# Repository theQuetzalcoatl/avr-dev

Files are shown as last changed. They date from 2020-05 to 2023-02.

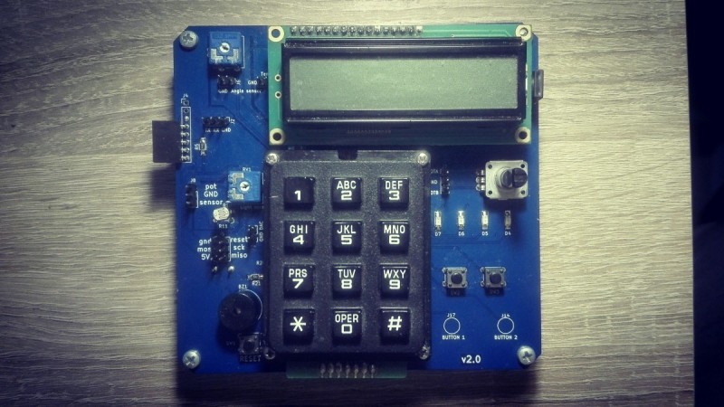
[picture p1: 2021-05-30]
HW/pictures/v2_0_full.jpg

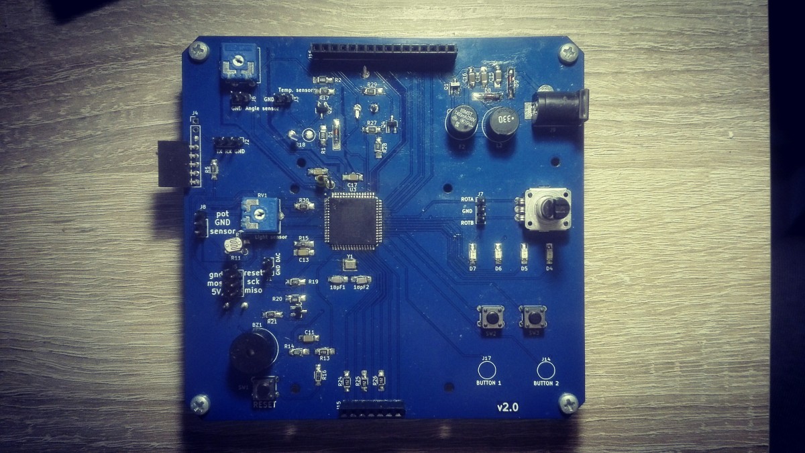
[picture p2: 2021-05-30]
HW/pictures/v2_0_nude.jpg

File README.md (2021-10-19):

# avr-dev

A self made and designed embedded development board with several peripherals/devices to use. On top of that is an embedded kernel with several device drivers, forming an OS.</br>
The project aims to develop a suitable SW architecture and a corresponding HW development board, which can be the foundation of learning and experimentation.

### [Hardware](https://github.com/theQuetzalcoatl/avr-dev/blob/master/HW/README.md "Hardware"):

* LCD
* DAC
* Buzzer
* LEDs & buttons
* Keypad
* UART (potentially USB)
* Temperature sensing
* Light sensing
* Capacitive touch sensing
* Voltage/angle sensing
* Rotary encoder

### [Software](https://github.com/theQuetzalcoatl/avr-dev/blob/master/SW/Application/README.md "Software"):

* A primitive, embedded OS
* Device drivers for HAL
* Application

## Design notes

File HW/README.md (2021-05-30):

# Hardware

This file is intended to keep track and present the more detailed informations about the HW part of the project.
The PCB is currently developed in KiCAD. 
---
### HW elements:
* **DAC**: A first order RC low pass filter with variing duty cycle PWM on its input
* **LCD**: A 2x16 display. Backlight can be switched on/off by SW
* **Buzzer**: MOSFET switched, frequency can be set by SW
* **LEDS & buttons**: 4 leds, two push buttons without external pullup resistors
* **Keypad**: a simple 3 by 4 one</br>
      |1|2|3|</br>
      |4|5|6|</br>
      |7|8|9|</br>
      |*|0|#|</br>
* **UART**: Jumper pins for UART  communication, with a suitable connector USB is possible using the CH340G based USB/UART module
* **Temp sensing**: A PT1000 and a current source is used
* **Light sensing**: An LDR is used alongside a regular pot. meter so treshold can also be set
* **Capacitive touch sensing**: Two buttons are made with using only one GPIO each
* **Voltage/angle sensing**: A regular pot meter will supply the devided Vcc voltage. It can be turned and as such, can be used as an angle sensor
* **Rotary encoder**: Capacitors are placed on the MCU pins to help with debouncing

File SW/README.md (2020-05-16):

# Software

This file is intended to keep track of and present the more detailed informations about the SW part of the project.
Explanation of folder structure, compilation how to etc... will be discussed here.
---
### Versioning: *TBD*

### How to compile:

#### known bugs, errors:

### Coding guideline:

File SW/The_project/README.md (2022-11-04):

**Versioning**: 

Right now somewhat arbitrary, but a **major.minor** is being used</br>
*major*: The change forces the user to use the SW a different way. E.g. A feature is cut, an API has changed, new build environment etc.</br>
*minor*: Changes may not directly affect the user. E.g. Bugfixes, efficiency improvement, internal restructuring etc.

**How to compile**:</br>
*  ./build.sh        (only compilation)</br>
*  ./build.sh upload (for burning as well)
___
### Aztec</br>
A lightweight, monolithic, real time embedded OS for AVR chips.
* Preemptive, using time slicing scheduling(Round Robin)
* Configurable stack size for each thread
* Stack overflow detection
* Device driver integration for the HW
* Currently 10 system calls
* Scripts for better, safer code quality
* Relatively configurable
* Mistake-proof</br>
  * stack sizes are checked for minimum & maximum
  * cannot register multiple threads using the same stack
  * min. max. system tick check, based on pysical calculations

#### Driver system</br>

##### **Related syscalls, functions**:
* _register_device_ - initializes and notifies the kernel of its existance, provides init checking upon leasing and ownership handling
* _lease_ - checks device initialization and its owner. If not owned it will be by the calling thread, if owned, an error will be raised by the kernel
* _release_ - tries to release the requested device. If the caller own it, it will be released, if not, error.
    If a thread exits without releasing any of its owned devices, the kernel releases them.
* _check_device_ownership_ - the developer of a driver can guard function calls to a device by checking the caller's ownership. It is not necessary, though.</br></br>
**Prepare a device for registration** by creating a directory under 'drivers'. Create at least an initialization function for it with type void and no arguments, and lastly, add a device ID entry to the DEVICES_IDS enum in kernel.h and include the header file.

#### Notice
More threads and longer systick period lessen the wait syscalls' accuracy.</br>
Due to required minimal stack usage the theoritical absolute maximum number of threads is about 89.</br>
Each Thread's stack usage should be estimated by the user.</br>
Threads should be exited with the proper syscall and not with a **return** statement.</br>

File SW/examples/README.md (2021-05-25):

**How to compile:**
	$ ./build_n_burn.sh <sourcefile_name>
	
**example:**
	$ ./build_n_burn.sh buttons.c

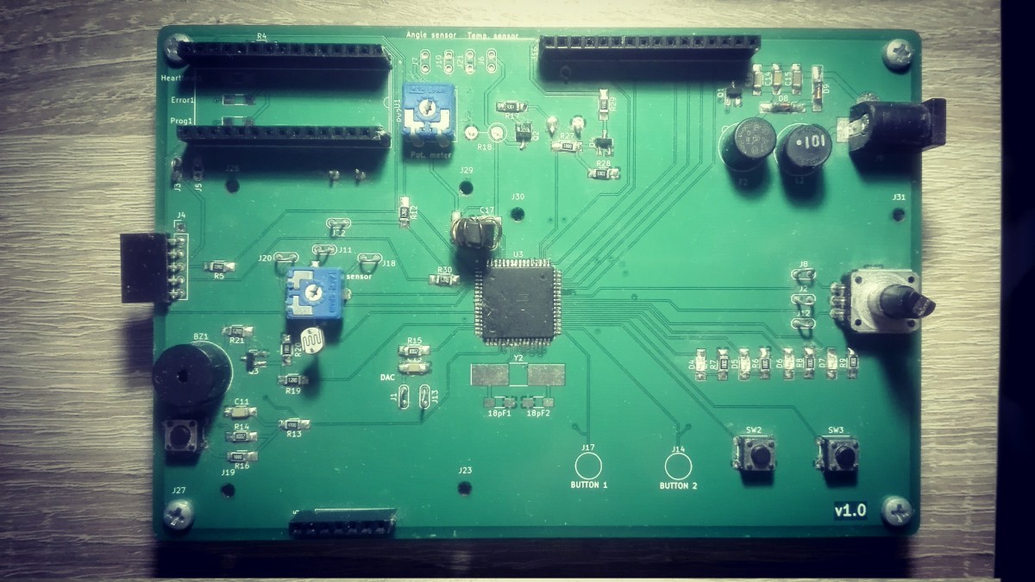
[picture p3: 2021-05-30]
HW/pictures/v1_0_nude.jpg

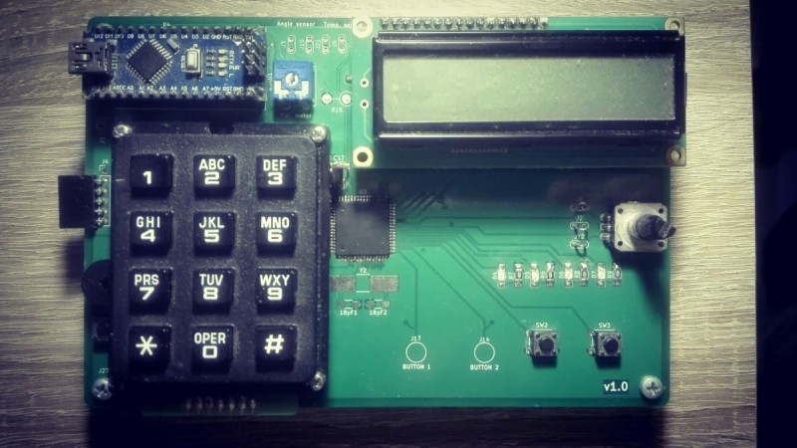
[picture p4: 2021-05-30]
HW/pictures/v1_0_full.jpg

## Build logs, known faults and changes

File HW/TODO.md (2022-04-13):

* [x] Make the corners round
* [x] Add version on silkscreen
* [x] Mark pin 1 of ICs with different pad than the others
* [x] Make all leds consume about 10-15 mA
* [x] Change pins of every button to fit into footprint
* [x] Low ohm resistors to the USART signals, to reduce possible crosstalk
* [-] Elongate the main MCU pads for easier soldering + easier removing of solder bridges.
* [x] Eliminate most of the  90° traces

---------------- v2.0 ----------------------

* [x] Separate Arduino programmer from the board, only SPI connectrions shall remain
* [x] Change the connector pinout to the USB/UART module to have it 5V
* [x] Change position of C17,C9 and L1
* [x] Use one resistor for Tx pin insted of R30 and R12
* [x] Rotary encoder's case shall be grounded
* [x] Led resistors to the back side
* [x] Separate the analogue circuitries from each other.
* [x] Change the GND and VCC planes.
* [x] 5V Jack connector side fuse shall be placed before the zener diodes
* [-] Delete the voltage/angle sensor, a.k.a. pot meter and the one which is used for Analoge Comparison should be moved to one of the ADC multiplexer pins so it can be used for both.
			Additionally, the placement of the pot. meter should be considered as it may get a handle or something. 
* [x] Add Zner diode + resistor to tie the BJT's base to a lower voltage level in order to be able to function as current generator
* [-] Re-order the pinout to the keyboard
* [x] Reverse the order of leds to be able to visually represent binariy counting bits etc.. because right now it is backwards

---------------- v3.0 ----------------------

* [-] Shrink the ground connection to the PT1000 in order to make it able to represent the *air's* temperature - not so critical, besides, PCB temp is much more stable
* [x] Male headers in series with DC jack input to be able to measure input current.
* [x] Create a proper footprint for the UART 90° connector.
* [-] Push buttons shall be SMD
* [X] Insert LED1..LED4 for leds instead of D4..D7
* [x] Add a 4 pin male header connected to GND for easier access to GND.
* [x] Remove D9 Zener diode because it is eesentially not needed when it comes to negative input voltage
* [x] Replace input DC jack connector with an USB one.

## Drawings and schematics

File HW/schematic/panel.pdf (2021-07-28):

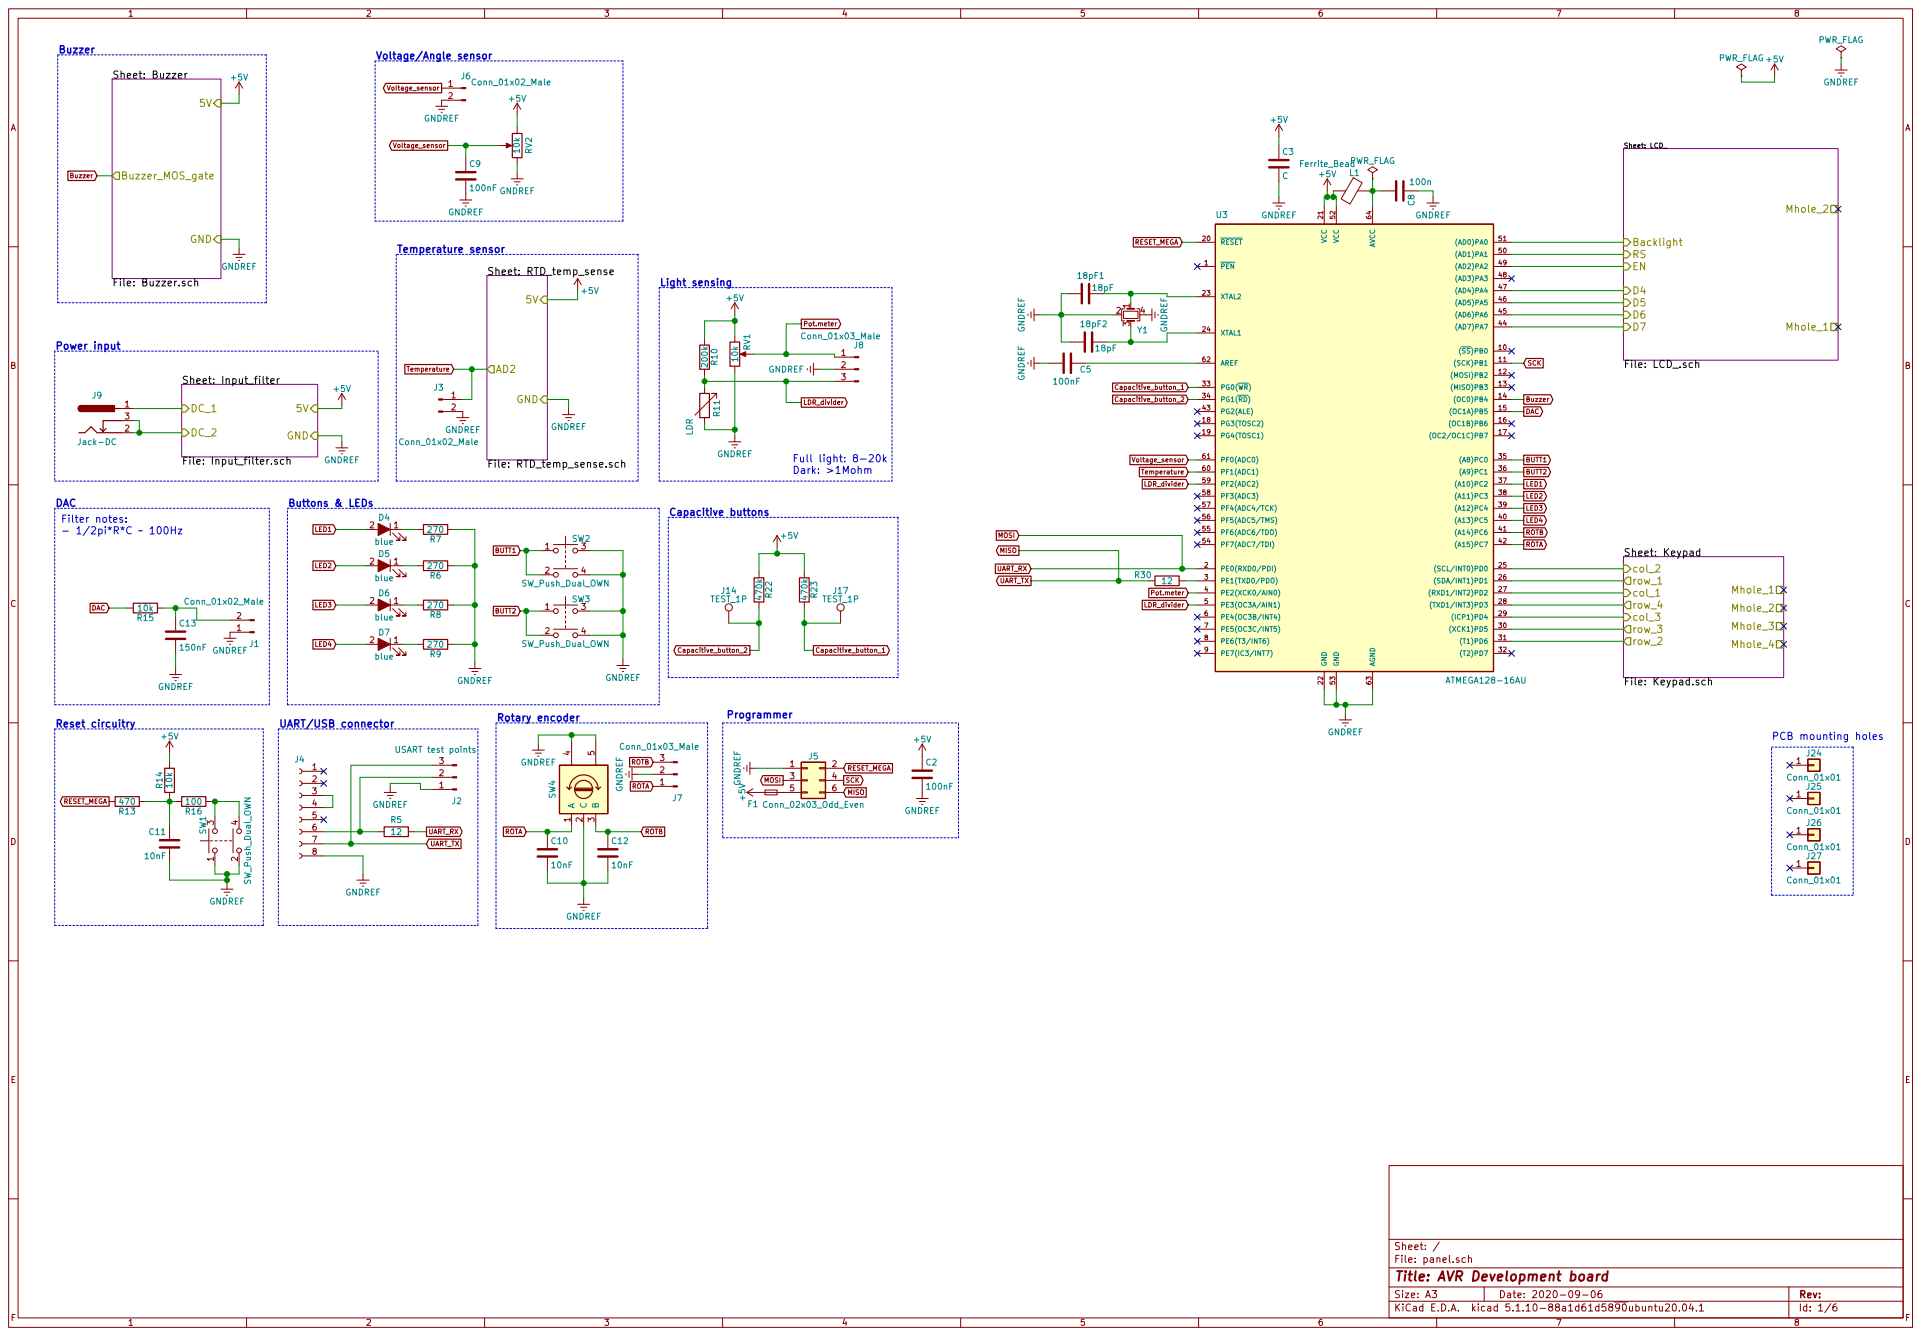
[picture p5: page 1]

Sheet: Buzzer File: Buzzer.sch Buzzer_MOS_gate
J7 Conn_01x03_Male GNDREF GNDREF

File: panel.sch Sheet: /
Id: 1/6 Title: AVR Development board

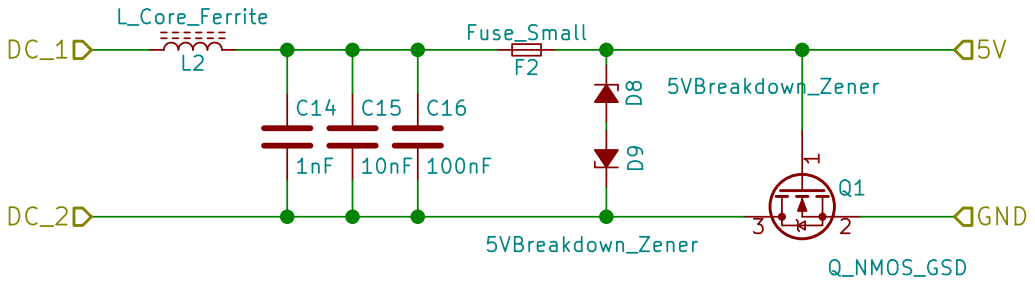
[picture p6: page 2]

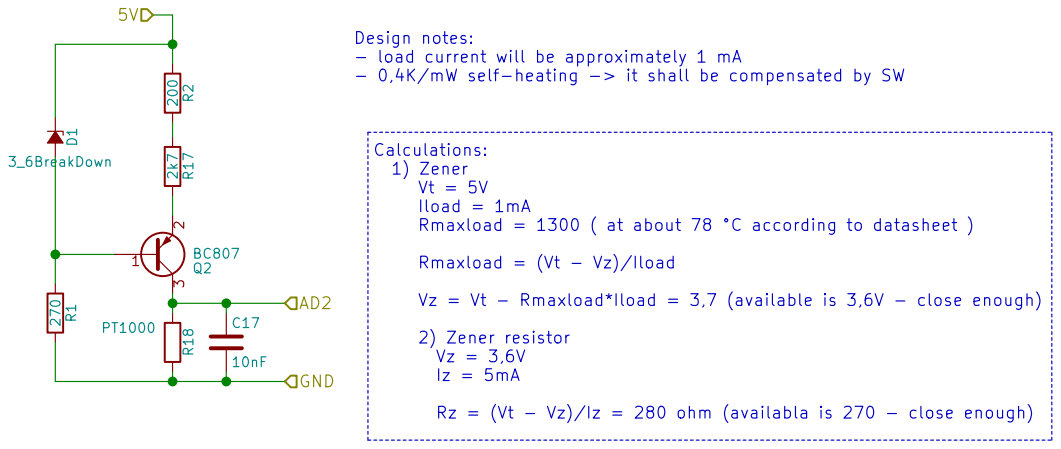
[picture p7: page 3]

Design notes:
- load current will be approximately 1 mA
- 0,4K/mW self-heating -> it shall be compensated by SW

1) Zener
Iload = 1mA
Rmaxload = 1300 ( at about 78 °C according to datasheet )

Rmaxload = (Vt - Vz)/Iload

Vz = Vt - Rmaxload*Iload = 3,7 (available is 3,6V - close enough)

Rz = (Vt - Vz)/Iz = 280 ohm (availabla is 270 - close enough)

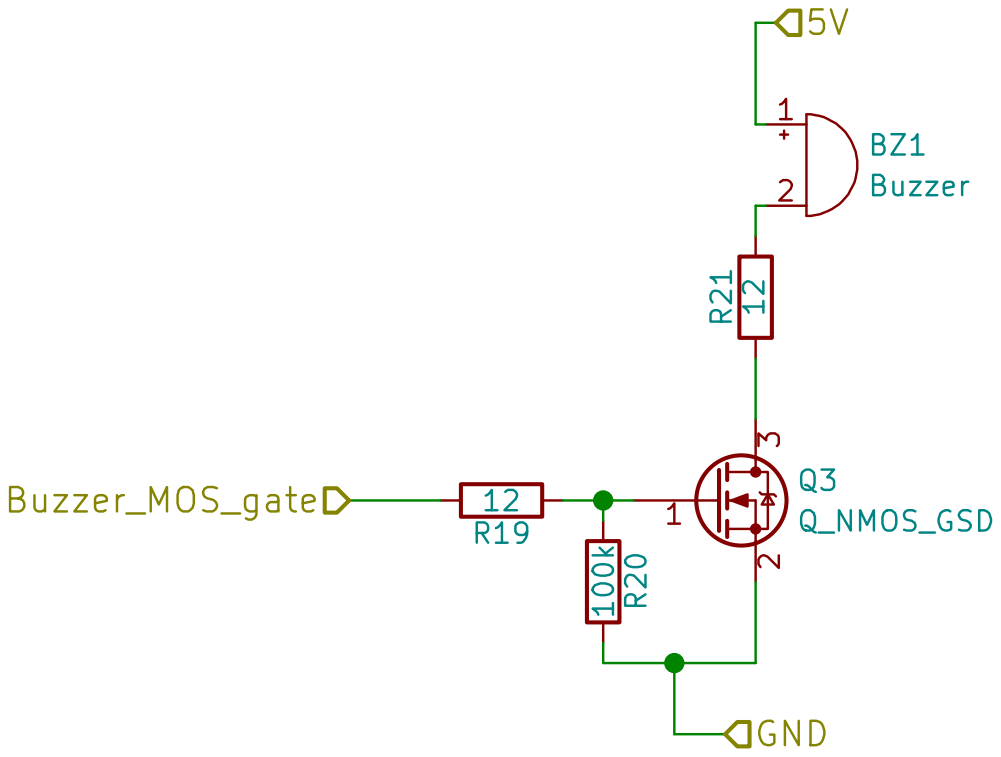
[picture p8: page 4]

Id: 4/6 Title: File: Buzzer.sch Sheet: /Buzzer/

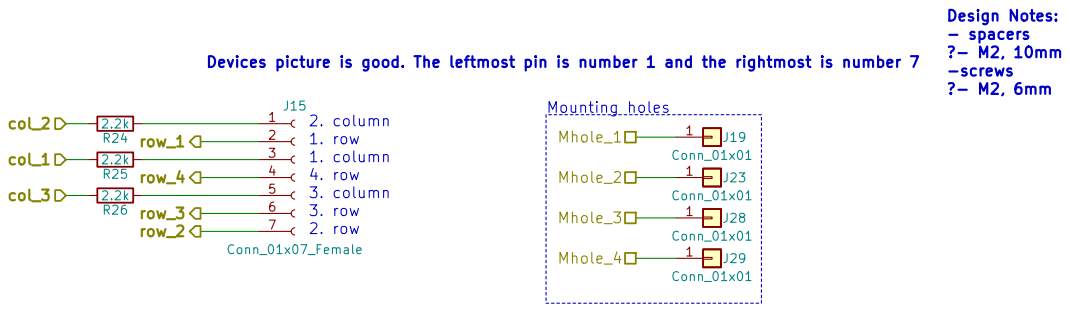
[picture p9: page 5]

Devices picture is good. The leftmost pin is number 1 and the rightmost is number 7

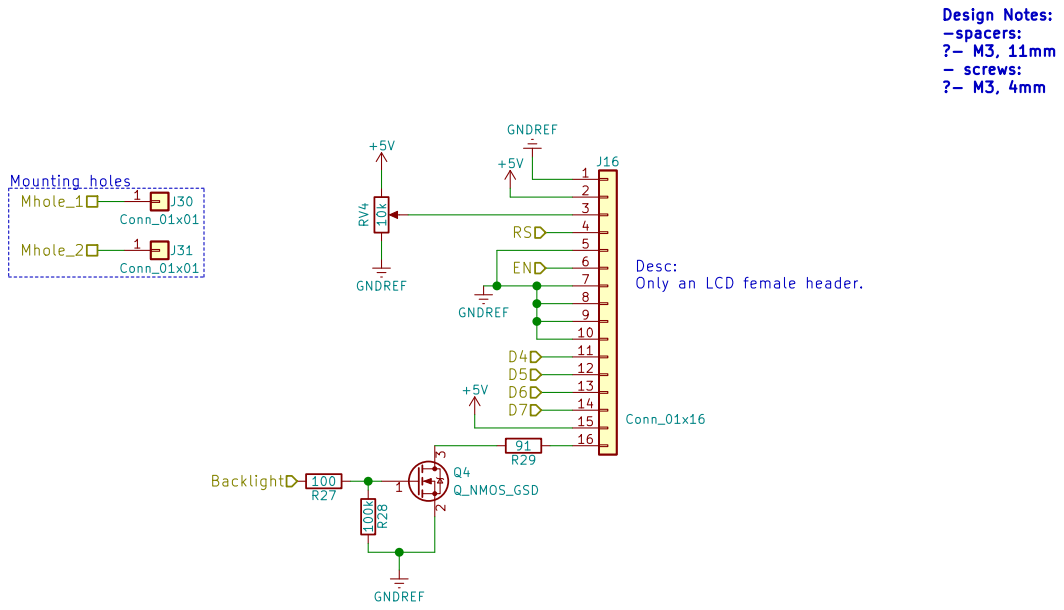
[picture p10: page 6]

Desc: Only an LCD female header.

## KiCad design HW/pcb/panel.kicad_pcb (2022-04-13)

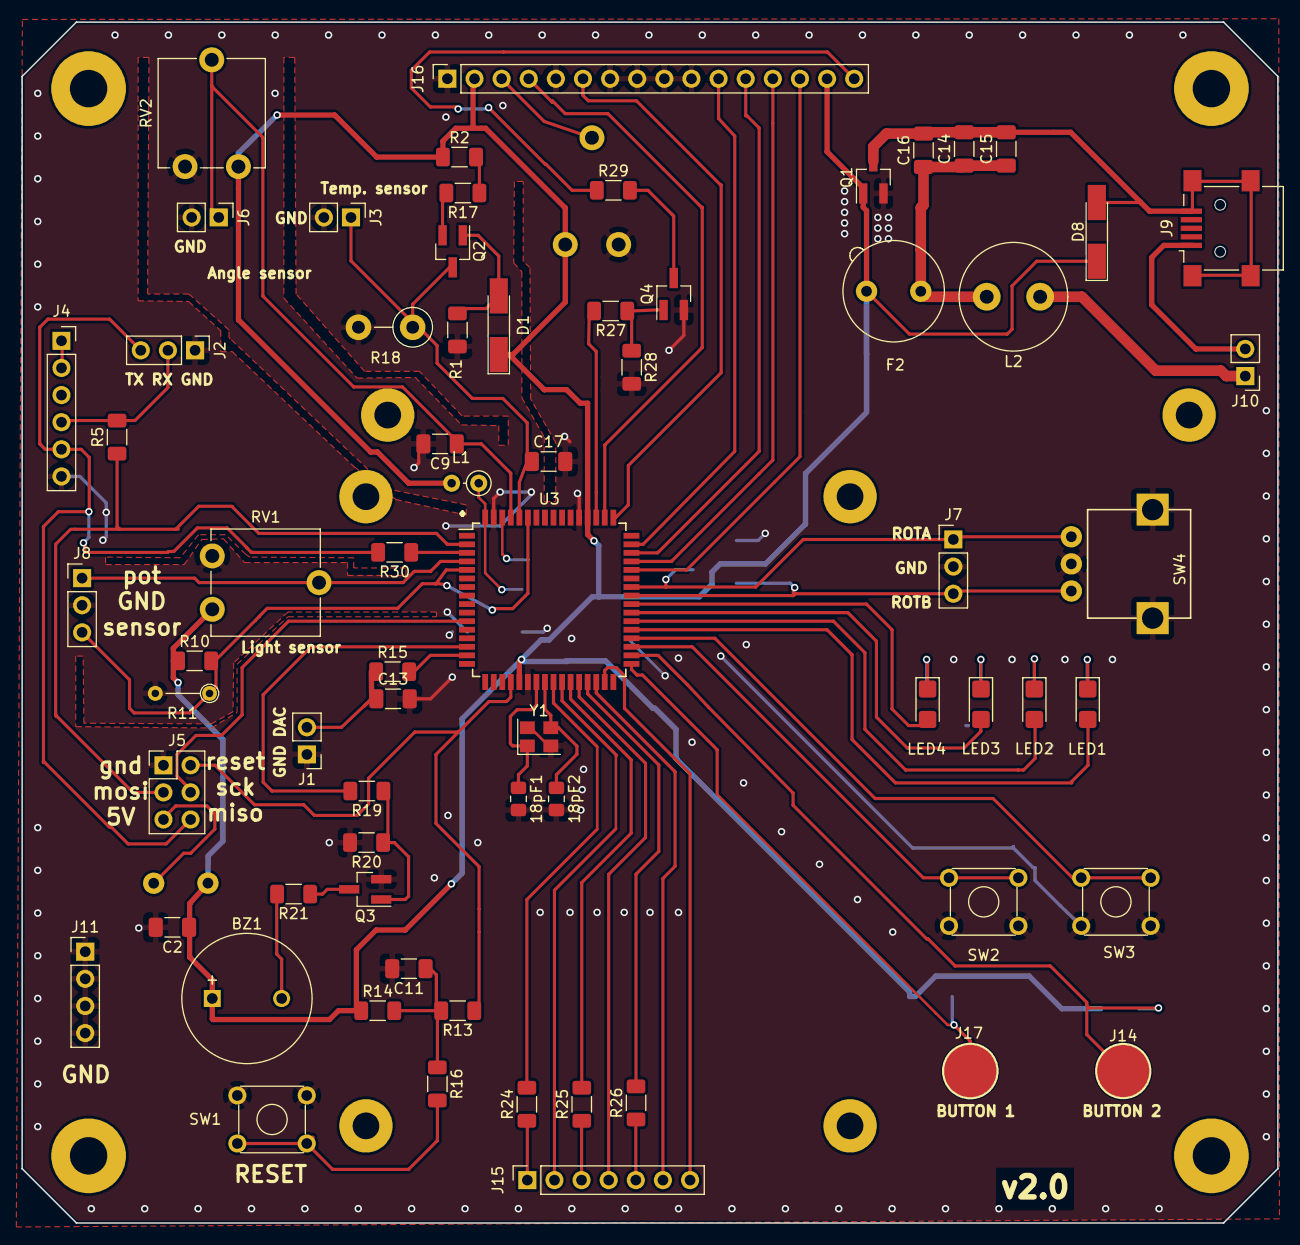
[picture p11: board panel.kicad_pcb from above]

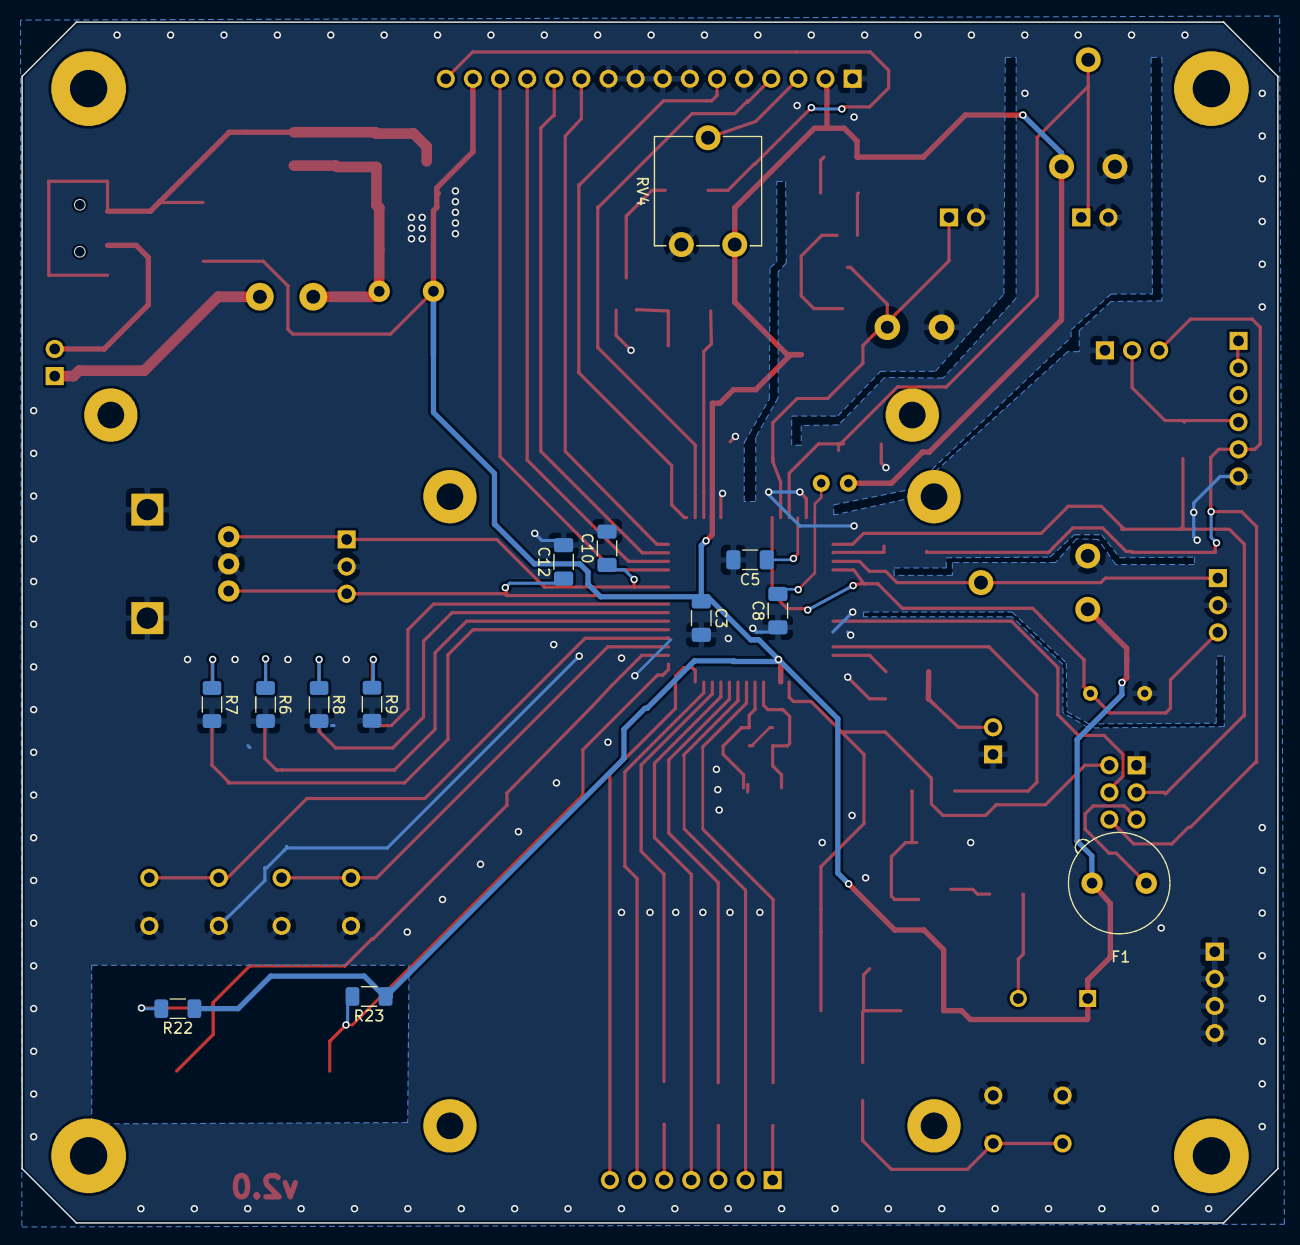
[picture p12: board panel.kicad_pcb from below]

Board: 2 copper layers, 117.6 x 112.5 mm, 91 parts (13 on the bottom side), 68 nets.

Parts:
18pF1, 18pF2: 18pF; C_0805_2012Metric_Pad1.18x1.45mm_HandSolder
BZ1: Buzzer; MagneticBuzzer_ProSignal_ABT-410-RC
C2, C5, C9, C16: 100nF; C_1206_3216Metric_Pad1.33x1.80mm_HandSolder
C3: C; C_1206_3216Metric_Pad1.33x1.80mm_HandSolder
C8: 100n; C_1206_3216Metric_Pad1.33x1.80mm_HandSolder
C10, C11, C12, C15, C17: 10nF; C_1206_3216Metric_Pad1.33x1.80mm_HandSolder
C13: 150nF; C_1206_3216Metric_Pad1.33x1.80mm_HandSolder
C14: 1nF; C_1206_3216Metric_Pad1.33x1.80mm_HandSolder
D1: 3_6BreakDown; D_MiniMELF_Handsoldering
D8: 5VBreakdown_Zener; D_MiniMELF_Handsoldering
F1, F2: Fuse_Small; Fuseholder_Fuse_TR5_Littlefuse-No560_No460
J1, J6: Conn_01x02_Male; PinHeader_1x02_P2.54mm_Vertical
J2: USART test points; PinHeader_1x03_P2.54mm_Vertical
J3: Conn_01x02_Male; Pin_Header_Straight_1x02_Pitch2.54mm
J4: uart_conn; PinSocket_1x06_P2.54mm_Vertical
J5: Conn_02x03_Odd_Even; PinHeader_2x03_P2.54mm_Vertical
J7, J8: Conn_01x03_Male; PinHeader_1x03_P2.54mm_Vertical
J9: USB_B_Mini; USB_Mini-B_Lumberg_2486_01_Horizontal
J10: current sense; PinHeader_1x02_P2.54mm_Vertical
J11: GND conn; PinHeader_1x04_P2.54mm_Vertical
J14, J17: TEST_1P; Measurement_Point_Round-SMD-Pad_Big
J15: Conn_01x07_Female; PinSocket_1x07_P2.54mm_Vertical
J16: Conn_01x16; PinSocket_1x16_P2.54mm_Vertical
J19, J23, J28, J29, J30, J31: Conn_01x01; MountingHole_2.5mm_Pad
J24, J25, J26, J27: Conn_01x01; MountingHole_3.5mm_Pad
L1: Ferrite_Bead; L_Axial_L5.3mm_D2.2mm_P2.54mm_Vertical_Vishay_IM-1
L2: L_Core_Ferrite; L_Radial_D10.0mm_P5.00mm_Fastron_07M
LED1, LED2, LED3, LED4: blue; LED_1206_3216Metric_Castellated
Q1, Q3, Q4: Q_NMOS_GSD; SOT-23_Handsoldering
Q2: BC807; SOT-23_Handsoldering
R1, R6, R7, R8, R9: 270; R_1206_3216Metric_Pad1.30x1.75mm_HandSolder
R2: 200; R_1206_3216Metric_Pad1.30x1.75mm_HandSolder
R5, R19, R21, R30: 12; R_1206_3216Metric_Pad1.30x1.75mm_HandSolder
R10: 200k; R_1206_3216Metric_Pad1.30x1.75mm_HandSolder
R11: LDR; R_Axial_DIN0204_L3.6mm_D1.6mm_P5.08mm_Vertical
R13: 470; R_1206_3216Metric_Pad1.30x1.75mm_HandSolder
R14, R15: 10k; R_1206_3216Metric_Pad1.30x1.75mm_HandSolder
R16, R27: 100; R_1206_3216Metric_Pad1.30x1.75mm_HandSolder
R17: 2k7; R_1206_3216Metric_Pad1.30x1.75mm_HandSolder
R18: PT1000; R_Axial_DIN0411_L9.9mm_D3.6mm_P5.08mm_Vertical
R20, R28: 100k; R_1206_3216Metric_Pad1.30x1.75mm_HandSolder
R22, R23: 470k; R_1206_3216Metric_Pad1.30x1.75mm_HandSolder
R24, R25, R26: 2.2k; R_1206_3216Metric_Pad1.30x1.75mm_HandSolder
R29: 91; R_1206_3216Metric_Pad1.30x1.75mm_HandSolder
RV1, RV2, RV4: 10k; Potentiometer_ACP_CA9-V10_Vertical
SW1, SW2, SW3: SW_Push_Dual_OWN; SW_TH_Tactile_Omron_B3F-10xx
SW4: Rotary_Encoder_With_CaseHolder; Rotary_Encoder_CaseHolder
U3: ATMEGA128-16AU; TQFP-64_14x14mm_P0.8mm
Y1: Crystal_GND24_Small; Crystal_SMD_3225-4Pin_3.2x2.5mm

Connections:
+5V: BZ1.1, C2.1, C3.1, D1.1, D8.1, F1.2, F2.2, J16.2, J16.15, L1.2, Q1.1, R2.1, R10.1, R14.1, R22.1, R23.1, RV1.1, RV2.1, RV4.1, U3.21, U3.52
/Input_filter/DC_1: J9.1, J10.2
/Input_filter/DC_2: C14.2, C15.2, C16.2, D8.2, J9.5, J9.6, Q1.3
/Keypad/col_1: R25.2, U3.27
/Keypad/col_2: R24.2, U3.25
/Keypad/col_3: R26.2, U3.29
/Keypad/row_1: J15.2, U3.26
/Keypad/row_2: J15.7, U3.31
/Keypad/row_3: J15.6, U3.30
/Keypad/row_4: J15.4, U3.28
/LCD_/Backlight: R27.2, U3.51
/LCD_/D4: J16.11, U3.47
/LCD_/D5: J16.12, U3.46
/LCD_/D6: J16.13, U3.45
/LCD_/D7: J16.14, U3.44
/LCD_/EN: J16.6, U3.49
/LCD_/RS: J16.4, U3.50
BUTT1: SW2.1, SW2.2, U3.35
BUTT2: SW3.1, SW3.2, U3.36
Buzzer: R19.2, U3.14
Capacitive_button_1: J17.1, R23.2, U3.33
Capacitive_button_2: J14.1, R22.2, U3.34
DAC: R15.2, U3.15
GNDREF: 18pF1.2, 18pF2.2, C2.2, C3.2, C5.2, C8.1, C9.2, C10.2, C11.2, C12.2, C13.2, C17.2, J1.1, J2.1, J3.2, J4.6, J5.1, J6.2, J7.2, J8.2, J11.1, J11.2, J11.3, J11.4, J16.1, J16.5, J16.7, J16.8, J16.9, J16.10, Q1.2, Q3.2, Q4.2, R1.2, R6.2, R7.2, R8.2, R9.2, R11.2, R18.2, R20.2, R28.2, RV1.3, RV2.3, RV4.3, SW1.1, SW1.2, SW2.3, SW2.4, SW3.3, SW3.4, SW4.2, SW4.4, SW4.5, U3.22, U3.53, U3.63, Y1.2, Y1.4
LDR_divider: J8.3, R10.2, R11.1, U3.5, U3.59
LED1: LED1.2, U3.37
LED2: LED2.2, U3.38
LED3: LED3.2, U3.39
LED4: LED4.2, U3.40
MISO: J2.3, J4.5, J5.6, R30.2
MOSI: J5.3, R5.1, U3.2
unnamed: 18pF1.1, U3.23, Y1.1
unnamed: 18pF2.1, U3.24, Y1.3
unnamed: BZ1.2, R21.2
unnamed: C5.1, U3.62
unnamed: C8.2, L1.1, U3.64
unnamed: C11.1, R13.2, R14.2, R16.1
unnamed: C13.1, J1.2, R15.1
unnamed: C14.1, C15.1, C16.1, F2.1, L2.2
unnamed: D1.2, Q2.1, R1.1
unnamed: F1.1, J5.5
unnamed: J2.2, J4.4, R5.2
unnamed: J4.1, J4.2
unnamed: J10.1, L2.1
unnamed: J15.1, R24.1
unnamed: J15.3, R25.1
unnamed: J15.5, R26.1
unnamed: J16.3, RV4.2
unnamed: J16.16, R29.1
unnamed: LED1.1, R7.1
unnamed: LED2.1, R6.1
unnamed: LED3.1, R8.1
unnamed: LED4.1, R9.1
unnamed: Q2.2, R17.2
unnamed: Q3.1, R19.1, R20.1
unnamed: Q3.3, R21.1
unnamed: Q4.1, R27.1, R28.1
unnamed: Q4.3, R29.2
unnamed: R16.2, SW1.3, SW1.4
unnamed: R2.2, R17.1
unnamed: R30.1, U3.3
Pot.meter: J8.1, RV1.2, U3.4
RESET_MEGA: J5.2, R13.1, U3.20
ROTA: C10.1, J7.1, SW4.1, U3.42
ROTB: C12.1, J7.3, SW4.3, U3.41
SCK: J5.4, U3.11
Temperature: C17.1, J3.1, Q2.3, R18.1, U3.60
Voltage_sensor: C9.1, J6.1, RV2.2, U3.61

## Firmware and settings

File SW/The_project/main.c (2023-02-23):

#include "Aztec/kernel/kernel.h"
#include <stdlib.h>
#include <stdbool.h>

/***** Applications *****/

#include "./Applications/heartbeat/heartbeat.h"
#include "./Applications/lcd_backlight_monitor/lcd_backlight_monitor.h"
#include "./Applications/songs/songs.h"

/************************/


register_t kv_stack[CONFIG_MIN_STACK_SIZE + 20];
void display_kernel_version(void)
{
    lease(DEV_LCD);
    lease(DEV_LCD_LIGHT);
    lcd_turn_backligh_on();
    lcd_move_cursor(4,1);
    lcd_print("Aztec "KERNEL_VERSION" ");
    wait_ms(2000);
    lcd_send_command(LCD_CLEAR);
    load(main_heartbeat, heartbeat_stack, sizeof(heartbeat_stack));
    exit_();  // exiting without releasing the LCD -> kernel takes care of it
}

/***********************************************************************/

#define PARENT_MENU  (15u)
#define PRESENT_MENU (16u)
#define ACTION_MENU  (17u)

#define MENU_MARKER_UP   (0u)
#define MENU_MARKER_DOWN (1u)

#define DOWN      KEYPAD_0
#define UP        KEYPAD_5
#define ENTER     KEYPAD_9
#define EXIT      KEYPAD_7
#define ACTIVATE  KEYPAD_8

#define MENU_MARKER "*"

typedef struct menu_point_s
{
    char *name;
    struct menu_point_s *submenu;
    uint8_t type;
    uint8_t is_end;
    uint16_t (*action)(void);
}menu_point_s;


static uint16_t get_systick(void)
{
    return CONFIG_SYSTEM_TICK_IN_US;
}

static uint16_t get_sysclk(void)
{
    return F_CPU/1000000;
}

static uint16_t display_time(void)
{
    char c = 0;
    uint64_t uptime_s = 0;
    uint16_t hours = 0;
    uint8_t minutes = 0;
    uint8_t seconds = 0;
    uint8_t prev_seconds_val = seconds;
    char buffer[4] = {0};

    wait_ms(200); // Needed because otherwise we immideatly escape from the view.

    do{
        uptime_s = get_uptime();;
    
        hours = uptime_s/3600;
        uptime_s -= hours*3600;
    
        minutes = uptime_s/60;
        uptime_s -= minutes*60;

        seconds = uptime_s;

        if(seconds != prev_seconds_val){
            lcd_send_command(LCD_CLEAR);
            lcd_move_cursor(1,1);

            utoa(hours, buffer, 10);
            lcd_print(buffer);
            lcd_print(":");
            utoa(minutes, buffer, 10);
            lcd_print(buffer);
            lcd_print(":");
            utoa(seconds, buffer, 10);
            lcd_print(buffer);

            prev_seconds_val = seconds;
        }
        c = keypad_get_pressed_key_nonblocking();
    }while(c == KEYPAD_NO_NUM);

    return 0;
}

static uint16_t get_threads(void)
{
    return get_num_of_threads();
}

static bool buzzer_is_on = false;
static uint16_t toggle_buzzer_sound(void)
{
    buzzer_is_on = !buzzer_is_on;
    lease(DEV_BUZZER);
    return 0;
}


static uint16_t play_imp_march(void)
{
    release(DEV_BUZZER);
    load(imperial_march, song_stack, sizeof(song_stack));
    return 0;
}

static uint16_t play_tetris(void)
{
    release(DEV_BUZZER);
    load(tetris, song_stack, sizeof(song_stack));
    return 0;
}

static uint16_t play_gta(void)
{
    release(DEV_BUZZER);
    load(gta_sa_theme, song_stack, sizeof(song_stack));
    return 0;
}


register_t menu_stack[CONFIG_MIN_STACK_SIZE + 200];
void menu(void)
{
    wait_ms(1000);
    while(lease(DEV_BUZZER) != NO_ERROR){;}
    while(lease(DEV_LCD) != NO_ERROR){;}

    uint8_t menu_marker_pos = MENU_MARKER_UP;
    uint8_t menu_index = 0;
    char buffer[10] = {0};

    menu_point_s music_submenu[] = {
                                        [0] = {.name = "Imperial March", .type = ACTION_MENU, .action = &play_imp_march, .submenu = 0, .is_end = false},
                                        [1] = {.name = "Tetris", .type = ACTION_MENU, .action = &play_tetris, .submenu = 0, .is_end = false},
                                        [2] = {.name = "GTA SA", .type = ACTION_MENU, .action = &play_gta, .submenu = 0, .is_end = true}
                                    };

    menu_point_s sys_info_submenu[] = {
                                        [0] = {.name = "Threads  - ", .type = PRESENT_MENU, .action = &get_threads, .submenu = 0, .is_end = false},
                                        [1] = {.name = "Systicks - ", .type = PRESENT_MENU, .action = &get_systick, .submenu = 0, .is_end = false},
                                        [2] = {.name = "Clock[MHz] - ", .type = PRESENT_MENU, .action = &get_sysclk, .submenu = 0, .is_end = false},
                                        [3] = {.name = "Uptime        >", .type = ACTION_MENU, .action = &display_time, .submenu = 0, .is_end = true},
                                      };

    menu_point_s keypad_submenu[] = {
                                        [0] = { .name = "On/Off", .type = ACTION_MENU, .action = &toggle_buzzer_sound, .submenu = 0, .is_end = false},
                                        [1] = { .name = " ", .type = ACTION_MENU, .action = 0, .submenu = 0, .is_end = true},
                                    };

    menu_point_s main_menu_points[] = {
                                        [0] = {.name = "Music         >", .type = PARENT_MENU, .action = 0, .submenu = music_submenu, .is_end = false},
                                        [1] = {.name = "System info   >", .type = PARENT_MENU, .action = 0, .submenu = sys_info_submenu, .is_end = false},
                                        [2] = {.name = "Keypad sound  >", .type = PARENT_MENU, .action = 0, .submenu = keypad_submenu, .is_end = false},
                                        [3] = {.name = "Games         >", .type = PARENT_MENU, .action = 0, .submenu = 0, .is_end = true},
                                    };

    menu_point_s *current_menu_point = main_menu_points;

    do{
        lease(DEV_BUZZER); // try to get back buzzer
         /* refresh lcd */
        lcd_send_command(LCD_CLEAR);
        wait_ms(2); /* needed because we can be too fast and print out garbage */
        if(menu_marker_pos == MENU_MARKER_UP){
            lcd_print(MENU_MARKER);
            lcd_print(current_menu_point->name);
            if(current_menu_point->action != 0){
                if(current_menu_point->type == PRESENT_MENU){
                    utoa(current_menu_point->action(), buffer, 10);
                    lcd_print(buffer);
                }
            }
            lcd_move_cursor(2,2);
            lcd_print((current_menu_point+1)->name);
            if((current_menu_point + 1)->action != 0){
                if((current_menu_point + 1)->type == PRESENT_MENU){
                    utoa((current_menu_point + 1)->action(), buffer, 10);
                    lcd_print(buffer);
                }
            }
        }
        else{
            lcd_move_cursor(2,1);
            lcd_print((current_menu_point - 1)->name);
            if((current_menu_point - 1)->action != 0){
                if((current_menu_point - 1)->type == PRESENT_MENU){
                    utoa((current_menu_point - 1)->action(), buffer, 10);
                    lcd_print(buffer);
                }
            }
            lcd_move_cursor(1,2);
            lcd_print(MENU_MARKER);
            lcd_print((current_menu_point)->name);
            if(current_menu_point->action != 0){
                if(current_menu_point->type == PRESENT_MENU){
                    utoa(current_menu_point->action(), buffer, 10);
                    lcd_print(buffer);
                }
            }
        }

        char key = keypad_get_pressed_key();
        switch(key)
        {
            case DOWN:
                if(current_menu_point->is_end == false) {
                    ++menu_index;
                    ++current_menu_point;
                    if(menu_marker_pos == MENU_MARKER_UP) menu_marker_pos = MENU_MARKER_DOWN;
                }
                break;

            case UP:
                if(menu_index > 0){
                    --menu_index;
                    --current_menu_point;
                    if(menu_marker_pos == MENU_MARKER_DOWN) menu_marker_pos = MENU_MARKER_UP;
                }
                break;

            case ENTER:
                if(current_menu_point->type == PARENT_MENU && current_menu_point->submenu != 0){
                    current_menu_point = current_menu_point->submenu;
                    menu_index = 0;
                    menu_marker_pos = MENU_MARKER_UP;
                }
                break;

            case EXIT:
                current_menu_point = main_menu_points;
                menu_index = 0;
                menu_marker_pos = MENU_MARKER_UP;
                break;

            case ACTIVATE:
                if(current_menu_point->action != 0) current_menu_point->action();
                break;
        }

        if(buzzer_is_on){
            buzzer_buzz(350);
            wait_ms(100);
            buzzer_off();
            wait_ms(50);
        }
        else wait_ms(150);
        
    }while(1);
}


/***********************************************************************/


int main(void)
{
    register_device(button_init_device, DEV_BUTTON);
    register_device(led_init_device, DEV_LED1); 
    register_device(led_init_device, DEV_LED2); // multiple init function for different devices
    register_device(led_init_device, DEV_LED3);
    register_device(led_init_device, DEV_LED4);
    register_device(lcd_init_device, DEV_LCD);
    register_device(uart_init_device, DEV_UART);
    register_device(buzzer_init_device, DEV_BUZZER);
    register_device(adc_init_device, DEV_ADC);
    register_device(lcd_init_backlight, DEV_LCD_LIGHT);
    keypad_init_device(); // devices need not be registered by the kernel

    register_thread(display_kernel_version, kv_stack, sizeof(kv_stack));
    register_thread(menu, menu_stack, sizeof(menu_stack));
    register_thread(lcd_backlight_monitor_main, lcd_backlight_monitor_stack, sizeof(lcd_backlight_monitor_stack));

    klog_init(uart_puts);

    klog_log("OH OOH, BIG PROBLEM");

    start_os();

    while(1){;} // just in case
 
    return 0;
}


/***********************************************************************/

/* user defined kernel panic, overwrites the default kernel one */
void kernel_panic(void)
{
    cli();
    DDRC |= 1<<LED3;
    while(1){
        for(uint8_t i = 3; i; --i){
            PORTC |= 1<<LED3;
            _delay_ms(100);
            PORTC &= ~(1<<LED3);
            _delay_ms(100);
        }
        for(uint8_t i = 3; i; --i){
            PORTC |= 1<<LED3;
            _delay_ms(300);
            PORTC &= ~(1<<LED3);
            _delay_ms(100);
        }
        for(uint8_t i = 3; i; --i){
            PORTC |= 1<<LED3;
            _delay_ms(100);
            PORTC &= ~(1<<LED4);
            _delay_ms(100);
        }
        _delay_ms(500);
    }
}

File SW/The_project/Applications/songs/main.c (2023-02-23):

#include "songs.h"
#include "stdbool.h"

#define A3 (220u)
#define C4 (261u)
#define B3 (246u)
#define D4 (293u)
#define E4 (329u)
#define G4 (392u)
#define B4 (493u)
#define C5 (523u)
#define G5 (783u)
#define Bb5 (932u)
#define C6 (1046u)
#define D6 (1174u)
#define Eb6 (1244u)
#define G6 (1567u)

register_t song_stack[CONFIG_MIN_STACK_SIZE + 20];


void tetris(void)
{
  lease(DEV_BUZZER);
  
  buzzer_buzz(E4);
  wait_ms(500);
    
  buzzer_buzz(B3);
  wait_ms(250);
  
  buzzer_buzz(C4);
  wait_ms(250);
  
  buzzer_buzz(D4);
  wait_ms(400);
  
  buzzer_buzz(C4);
  wait_ms(250);
  
  buzzer_buzz(B3);
  wait_ms(250);
  
  buzzer_buzz(A3);
  wait_ms(250);
  buzzer_off();
  wait_ms(120);
  
  buzzer_buzz(A3);
  wait_ms(250);
  
  buzzer_buzz(C4);
  wait_ms(250);
  
  buzzer_buzz(E4);
  wait_ms(400);
  
  buzzer_buzz(D4);
  wait_ms(250);
  
  buzzer_buzz(C4);
  wait_ms(250);
  
  buzzer_buzz(B3);
  wait_ms(500);
  buzzer_off();
  wait_ms(75);
  
  buzzer_buzz(C4);
  wait_ms(250);
  
  buzzer_buzz(D4);
  wait_ms(400);
  
  buzzer_buzz(E4);
  wait_ms(400);
  
  buzzer_buzz(C4);
  wait_ms(400);
  
  buzzer_buzz(A3);
  wait_ms(350);
  buzzer_off();
  wait_ms(75);
  
  buzzer_buzz(A3);
  wait_ms(350);
  buzzer_off();

  release(DEV_BUZZER);
  exit_();
}


void gta_sa_theme(void)
{
  lease(DEV_BUZZER);
  
  buzzer_buzz(G5);
  wait_ms(400);
  buzzer_off();
  wait_ms(70);
    
  buzzer_buzz(G6);
  wait_ms(400);
      
  buzzer_buzz(Eb6);
  wait_ms(300);
  buzzer_off();
  wait_ms(50);

  buzzer_buzz(D6);
  wait_ms(200);
      
  buzzer_buzz(Eb6);
  wait_ms(200);
      
  buzzer_buzz(D6);
  wait_ms(200);
      
  buzzer_buzz(C6);
  wait_ms(200);
      
  buzzer_buzz(D6);
  wait_ms(200);
  buzzer_off();
  wait_ms(150);
  
  buzzer_buzz(D6);
  wait_ms(600);
  buzzer_off();
  wait_ms(150);
    
  buzzer_buzz(Bb5);
  wait_ms(400);
  buzzer_off();
  wait_ms(50);
  
  buzzer_buzz(C6);
  wait_ms(200);
      
  buzzer_buzz(Bb5);
  wait_ms(200);
      
  buzzer_buzz(C6);
  wait_ms(400);
      
  buzzer_buzz(D6);
  wait_ms(300);
  buzzer_off();
  wait_ms(50);
  
  buzzer_buzz(G5);
  wait_ms(300);
  buzzer_off();
  wait_ms(30);
  
  buzzer_buzz(C6);
  wait_ms(300);
  buzzer_off();
  wait_ms(40);
  
  buzzer_buzz(Bb5);
  wait_ms(200);
      
  buzzer_buzz(G5);
  wait_ms(200);
  buzzer_off();

  release(DEV_BUZZER);
  exit_();
}


void imperial_march(void)
{
  lease(DEV_BUZZER);

  for(int i = 0; i < 3; ++i){
     buzzer_buzz(E4);
    wait_ms(550);
    buzzer_off();
    wait_ms(75);    
  }

  for(int i = 0; i < 2; ++i){
     buzzer_buzz(C4);
    wait_ms(450);
    buzzer_off();
    wait_ms(10);    

     buzzer_buzz(G4);
    wait_ms(200);
    buzzer_off();
    wait_ms(10);    

    buzzer_buzz(E4);
    wait_ms(550);
    buzzer_off();
    wait_ms(75);    
  }

  wait_ms(500);

  for(int i = 0; i < 3; ++i){
      buzzer_buzz(B4);
      wait_ms(550);
      buzzer_off();
      wait_ms(75);    
  }

  buzzer_buzz(C5);
  wait_ms(450);
  buzzer_off();
  wait_ms(10);

  buzzer_buzz(G4);
  wait_ms(200);
  buzzer_off();
  wait_ms(10);

  buzzer_buzz(E4);
  wait_ms(550);
  buzzer_off();
  wait_ms(75);

  buzzer_buzz(C4);
  wait_ms(450);
  buzzer_off();
  wait_ms(10);

  buzzer_buzz(G4);
  wait_ms(200);
  buzzer_off();
  wait_ms(10);

  buzzer_buzz(E4);
  wait_ms(550);
  buzzer_off();
  wait_ms(75);

  release(DEV_BUZZER);
  exit_();
}

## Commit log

2020-05-02 - Added HW/readme with some content - Updated System readme, corrected ADC->DAC - Updated some comments is SW Makefile - Added SW readme with some content
2020-05-02 Made a picture of what the board will roughly look like before it is made.
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2020-05-16 - Added TODO checklist for the board - Added a reminder comment for a nice idea in the Makefile
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2020-09-06 - Pictures of the new v1.0 were uploaded under HW/pictures - Schematic can be seen with all the sheets in HW/doc - Updated TODO for v2.0
2020-10-04 Corrected PORTB to LCD_PORT during the initialization.
    [lcd.c]
2020-10-07 * Created new, rotary encoder example source code * Modified the license statements at the end of some files
2020-10-29 * corrected GPL in some files * created new example code for the light sensor
    [comparator.c, rotary_encoder.c]
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2021-01-04 Added the gerber files.
    [panel_02-B.Cu.gbl, panel_02-B.Mask.gbs, panel_02-B.SilkS.gbo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]
2021-05-25 * Added the gerber files for the 2.0v of the board.
    [panel-B.Cu.gbl, panel-B.Mask.gbs, panel-B.SilkS.gbo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]
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2021-05-25 * TODO list updated, 2.0v checkpoints were carried out or denied. * READMEs were adjusted, simplified.
2021-05-25 * updated the examples to fit to the board 2.0v. * added temperature sensing example. * added fuse bit setting for 16 MHz external asc. and ATmega103 compatibility mode disabling
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2021-07-28 Added bullet points to TODO list for version 3 of the board.
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2021-07-28 Added entire KiCAD project.
    [Buzzer-2021-07-05-03-43-26.sch, Buzzer.sch, Capacitive_button.sch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]
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2021-07-30 * Removed current thread pointer - was not being used * removed 'id' from Thread struct, because it was not needed anywhere in the kernel
2021-07-30 Corrected the amount of minimal stack required by a thread * it was shorter by one, because I thought from 0 to 31 = 31. It does not.
2021-07-30 * Made the thread control block (tcb) a singly linked list insted of a simple array. * Scheduling algorithm is simpler (for now) * Threads come after another in a circular fashion
2021-07-31 Replaced C stack pointer storing instruction with less, faster assembly instructions. Now context switching is faster.
2021-08-01 * Eliminated all the avr/delay -> util/delay warnings * Implemented kernel exit functionality for threads * expanded the TCB with a pointer to the previous thread for easier deletion from the linked 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
2021-08-03 * Moved macros from kernel header to c file because currently they are only used in that module * Started adding guide comments to kernel APIs * By reseting TIMER0 at the end of every context restora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
2021-08-03 * the kernel now changes the deleted thread's state to 'DELETED' just in case it gets back to the linked list somehow. Then it won't be scheduled
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2021-08-06 * introduced minimal fatal error handling in 'kernel_panic' * will be used when an error cannot be corrected or dealt with by the kernel * continuously sends an S.O.S morse code to LED4.
    [main.c]
2021-08-06 * Changed a thread's address' type from snake case to camel case to be consistent with the other ones. * Decremented the minimum stack requirement because it still included RAMPZ register.
2021-08-06 * separated kernel error handling from the main code * kernel error code now prepended by a K * all future error handling shall take place in the error handling files
    * Corrected some error codes
    * Introduced new variable to TCB - num of active threads.
    * is reduced when a thread is halted.
    * will be used when a proper delaying mechanism will be implemented.
    * system now gently halts when the last one of the threads is being deleted.
    * implemented thread number checking
    [main.c]
2021-08-09 * Applied cast to operation in order to reduce generated assembly instruction by 2. (Not much, ut it's honest work)
2021-08-09 * Changed evaluation of which led should be dealt with because it is way faster, than the previous method.
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2021-08-09 * Moved ATOMIC operation to kernel header in order for the drivers to use. * Did not put 'extern void disable_systick(void)' into kernel header because it should only be reachable by the kernel and i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
2021-08-09 * An alive led * UART sending 'U' with delay when SW2 is pushed * Keypad's button presses appear on the LCD screen.
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2021-08-10 * Removed waiting ticks field form Thread struct because it has no use yet.
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2021-08-11 * Got system tick init closer to start of the function because if we shouldn't initialize the drivers if we could not init the systick * Fixed returning error code from init_system_ticking, as it is 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
2021-08-11 * char get_pressed_key --> keypad_get_pressed_key to be clear that that it is the keypad driver's API
2021-08-11 * Introduced 4th thread which should not be run according to the kernel configuration
2021-08-12 * Changed the kernel to use Timer 2 to generate the systick instead of Timer 0 because the Buzzer will use Timer 0 to generate sound. * Also changed the scaling of the systick based in microseconds i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
    [main.c]
2021-08-15 * Renamed TCB field to be shorter * Applied const qualifier where it was logical to do so.
    [main.c]
2021-08-15 * Properly made init function of the buzzer, which is mostly its timer's initialization * Added device functionalities * buzzing at a certain (unaccurate) frequency * safely stopping the buzzer
    [main.c]
2021-08-19 * Wrote notifying comments about the placement of fields in Thread and TCB data structures. * Corrected max MS tick's justification comment, prescaler was still the old value. * Made the task switch 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
    [main.c]
2021-08-19 * Introduced restrictions on the microcontroller frequency. For now, only 8 and 16MHz is allowed. * Introduced minimum systick , and it shall be 100 us. Because now a context switch is about 15 us. *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
2021-08-23 * Restructured exit syscall function * it now removes the current thread and invokes the scheduler for the next available task * Thread struct got a new field because of the waiting syscall * Restruc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
2021-08-24 * modified, added some comments for better understanding * Added const qualifiers where they were needed * Rearranged the function in kernel.c and created a SYSCALL section for more logical understan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
2021-08-24 * thread state definitions were moved to header, so the application code can use it when getting another thread's state * 'turn_led_on' and 'turn_led_off' functions got atomic write because of a bug 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
    [led.c, main.c]
2021-09-05 * Made 'kernel_get_thread_state' faster * it now uses a binary search * all the threads are sorted before scheduling is started * Reduced the maximum number of threads to 25, to be safe (an *educated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
2021-09-09 * Introduced kernel version for the application/driver layer which will be the latest tag number.
2021-09-23 * renaming from 'insert_stack_overflow_detection' to 'insert_stack_overflow_detecting_bytes' to be even more descriptive
    * in kernel_wait_us lowered the macro within the if statement because if we supply 0 to the function
    it will stay in ATOMIC forver...
2021-09-25 * started reforming the error handling system * introduced error type * maximum of 128 errors can be recognised by the kernel, with the MSB set to 1 * implemented stack registering checking. Now the 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
2021-09-26 * corrected macro name, microsencons(US) instead of milliseconds(MS)
    [main.c]
2021-10-12 * Changed driver system * Short: Now new function pair will be implemented(lease, release) which are analogous to 'open' and 'close'. The caller gets a device ID, and with it, can call certain functi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
    [button.c, button.h]
2021-10-12 * Changed driver system * Short: Now new function pair will be implemented(lease, release) which are analogous to 'open' and 'close'. The caller gets a device ID, and with it, can call certain functi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
    [led.c, led.h]
2021-10-12 * Updated main and utils to reflect the changes made to the driver system
2021-10-12 * Changed driver system * Short: Now new function pair will be implemented(lease, release) which are analogous to 'open' and 'close'. The caller gets a device ID, and with it, can call certain functi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
    * Corrected some typos
    * Introduced new kernel error : K_ERR_INVALID_DEVICE_ACCESS
    * Introduced device IDs
2021-10-16 * Introduced (re)leasing driver system to LCD. * applied atomic areas when leasing to make it safer, less concurrent. * created LCD driver ID in kernel
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2021-10-16 * Added atomic are to leasing * Extended the access checking in every function, because there could be a case, where noone is using the device, but the user thread has the ID somehow, and therefore c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
2021-10-19 * removed lease - release pair, as it is handled by the kernel. * now in critical functions, checking for ownership of the device
2021-10-19 * removed lease - release pair, as it is handled by the kernel. * now in critical functions, checking for ownership of the device * implemented internal command sending to simplfiy the initialization.
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2021-10-22 * Created a new lcd function 'lcd_print' to print strings. * created an internalwrite as well to be faster. * Also found a bug, at startup, if the first thread is run, and runs to exit before a conte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
    [lcd.c]
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2021-11-13 * Integrated Buzzer device into the kernel from driver side
2021-11-13 * Integrated Buzzer device from kernel side
2021-12-08 * Corrected some comments * Relocated device struct because 'release_owned_devices' uses it * Increased minimum systick to 300 us becuaseat 16 MHz it takes roughly 15 us to schedule and switch thread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
2021-12-12 * New driver functionality by the kernel * devices are initialization can go thourh the kernel, which helps ensuring that no device will be used withouth it being initialized. * 'init_device_drivers'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
2022-02-10 * Fixed button press bug * when pushing down SW3, it was not recognised, only SW2
    [button.c]
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2022-03-19 * changed 'buzzer' driver to 'sound' to be more general
2022-03-19 * Corrected 'sound' driver inclusion path
2022-04-13 Committing temporary PCB changes
    [Buzzer.sch, Input_filter.sch, Keypad.sch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]
2022-04-13 Implemented offset correction,with a known bug. It will be dealt with later
    [adc.c, adc.h]
2022-04-30 * Disable systick before resetting the uC. Because if not, it will jump to main and will wrongfully generate an interrupt, causing the system to crash.
2022-05-26 * introduced the possibility of running the kernel on other timer(s) than T2. For now only T0 is supported additionally. * + a bunch of file ID changes i guess, cause I switched to Ubuntu
    [Buzzer.sch, Input_filter.sch, Keypad.sch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]
2022-05-29 * implemented the showcase application, tetris song is still missing * menu system done * menu sound on/off done * system infos done * music - imperial march done
    [test_application.c]
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2022-12-13 * Changed the folder names not to interfere with bash scripts * Started creating new 'Application' section of the prtoject where independent threads can reside in their own environment
    [adc.c, adc.h, button.c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]
2023-02-23 * Moved the songs into Application territory in the folder structure * only have one, common stack * stop functionaliy is removed * intoduced 'load' syscall - hooks a not running thread with the supp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
    [main.c]
2025-04-26 Updated the way applications and the OS is built. Added some corrections and explanations.
    [button.c]
2026-01-02 Mostly implemented a new wait functionality. The only reason it does not work right now is that in fast PWM mode (WGM=14) the threshold register OCR1A is only updated when the timer reaches zero from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
